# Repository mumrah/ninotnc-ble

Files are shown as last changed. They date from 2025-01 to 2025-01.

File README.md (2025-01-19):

# NinoTNC BLE Expansion Board

This project brings robust and bi-directional Bluetooth connectivity to the
best amateur radio TNC on the market, the [NinoTNC](https://tarpn.net/t/nino-tnc/nino-tnc.html). This allows for the deployment of robust bi-directional APRS
at a low cost and in the DIY ham spirit.

The total cost for setting up an APRS mobile station using this project 
(excluding radio and antenna system) is around $80. 

* NinoTNC ($45 for DIY, more for pre-built)
* NinoBLE Expansion Board ($25 for pre-built, coming soon...)
* Custom TNC cable (free/cheap for DIY)
* APRS App (aprs.fi for iOS, APRSDroid for Android)

NinoTNC BLE Intro (https://youtu.be/kItOS-uezck "NinoTNC BLE Intro")

This project is experimental and should be considered as-is. The hardware and
firmware are open source licensed under the permissive MIT License.

# Features

* iOS and Android support
* Bi-directional APRS (receive and transmit)
* High-quality AFSK modulation, thanks to the NinoTNC
* USB powered using the USB-B connector on the NinoTNC
* Data logging to an on-board SD card
* Optional user-installed OLED display for packet information
* Pass-through mode for updating NinoTNC firmware

# Use Cases

## Mobile APRS

The most obvious and indeed the primary use case of this project. When set up
as described here, this board enables a very robust mobile APRS solution. Since
the NinoTNC is compatible with a wide range of 2m mobile radios (including
surplus commercial radios), the cost of the system can be kept low. 

The use of Bluetooth also allows for a "wireless" installation. There are no 
cables connected to the phone besides a charger. This allows for an arbitrary 
separation between the mobile phone and the TNC. The wireless range of the 
NinoBLE far exceeds any distance possible within a vehicle. 

## APRS Data Logging

The SD card located on the NinoBLE will log all packets sent and received.
This is quite useful when driving since logging in the APRS apps will
eventually roll off.

Each time the NinoBLE starts up, a new log file is created. This makes it
easy to find the most recent data, but also to retain the old data.

On-board data logging can also be useful for repeater operators who
occasionally have errant APRS traffic on their VHF repeaters. Logging
everything into the SD card makes it trivial to see who was accidentally
sending APRS traffic over the repeater.

## Portable APRS

If used with an HT, the NinoBLE can be used for portable APRS tracking. 
Since the APRS mobile apps use the phone's GPS, it is quite simple
to take this system into the field.

The same benefits of the Mobile APRS use case apply here. We can use 
inexpensive radios thanks to the high-quality DSP performed by the NinoTNC.

If the NinoBLE is equipped with the optional OLED screen, the NinBLE can be
used as a simple APRS receiver without a mobile phone.

## How it works

The primary function that this board adds to the NinoTNC is Bluetooth 
connectivity. There are many use cases for this besides APRS, but for now APRS 
is the focus of this project.

The expansion board is called the NinoBLE and connects physically to the NinoTNC
through the J5 header located under the USB to UART bridge. The NinoBLE board
replaces the USB to UART bridge that is normally installed on the TNC (at U4).

As KISS packets are received by the expansion board over Bluetooth, they are
decoded and forwarded to the UART interface. Similarly, when KISS data is
received over the UART, it is decoded and forwarded to the Bluetooth interface.

An optional SD card may be installed to capture the packets as they are sent andreceived.

## Hacking

The physical layout of the board is the only thing specific to the NinoTNC 
about this project. The electrical interface between the TNC and the expansion
board is 57600 baud UART and the data protocol used is KISS. This means that 
this project can be used to add Bluetooth to any KISS TNC that uses a UART.

The heart of this project is a RaspberryPi Pico W. Many of the GPIOs are unused,
so there is plenty of opportunity for expansion and tinkering.

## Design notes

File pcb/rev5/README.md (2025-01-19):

NinoTNC BLE rev5

The pogo pins (JLCPCB part number C5157269) are listed as Economy PCBA, but
really require Standard PCBA which is quite a bit more expensive. Also, the 
PCBA process for these pins is not super precise. All the boards I received 
had slight alignment issues. If you order this board, be sure to check the pins
for shorts.

In the next revision, I will source a different part for the pogo connector.

Files under the "fabrication" can be used for JLCPCB.

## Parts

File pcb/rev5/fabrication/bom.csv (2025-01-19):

Designator | Footprint | Quantity | Value | LCSC Part #
C1, C2 | 0805 | 2 | C | C28233
J1, J2, J6, J7 | Pin_D1.0mm_4.0mm_POGO | 4 | Conn_01x01 | C5157269
J3 | NinoTNC_No_J5 | 1 | Conn_01x01
J4 | SSD1306-0.91-OLED-4pin-128x32 | 1 | Conn_01x04
J5 | TF-01A | 1 | TF-01A | C91145
R1, R2 | 0805 | 2 | 10k | C17414
SW1 | SW_SPDT_CK_JS102011SAQN | 1 | SW_SPDT | C221660
SW2 | Panasonic_EVQPUL_EVQPUC | 1 | SW_Push | C79175
U1 | RPi_Pico_W_SMD_TH | 1 | Pico

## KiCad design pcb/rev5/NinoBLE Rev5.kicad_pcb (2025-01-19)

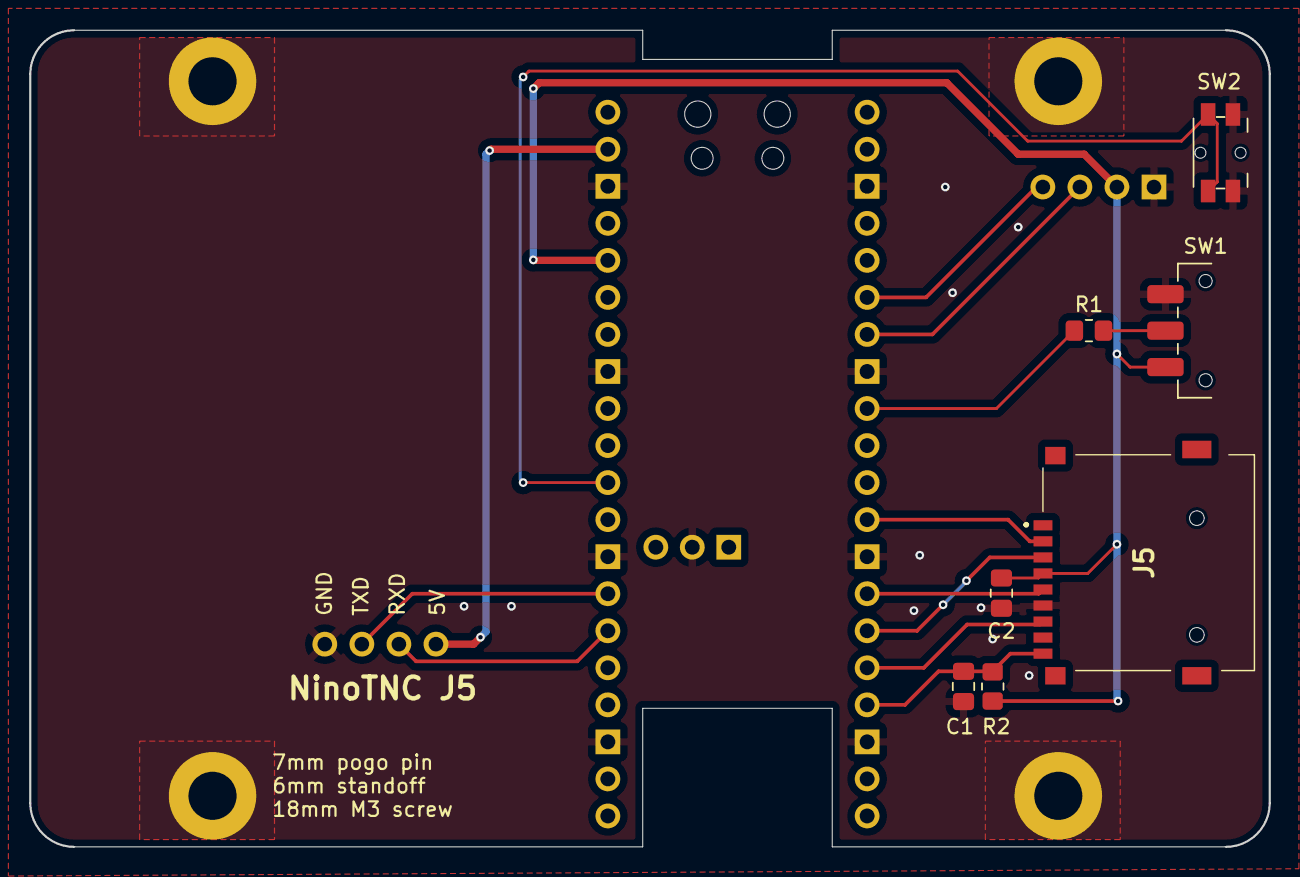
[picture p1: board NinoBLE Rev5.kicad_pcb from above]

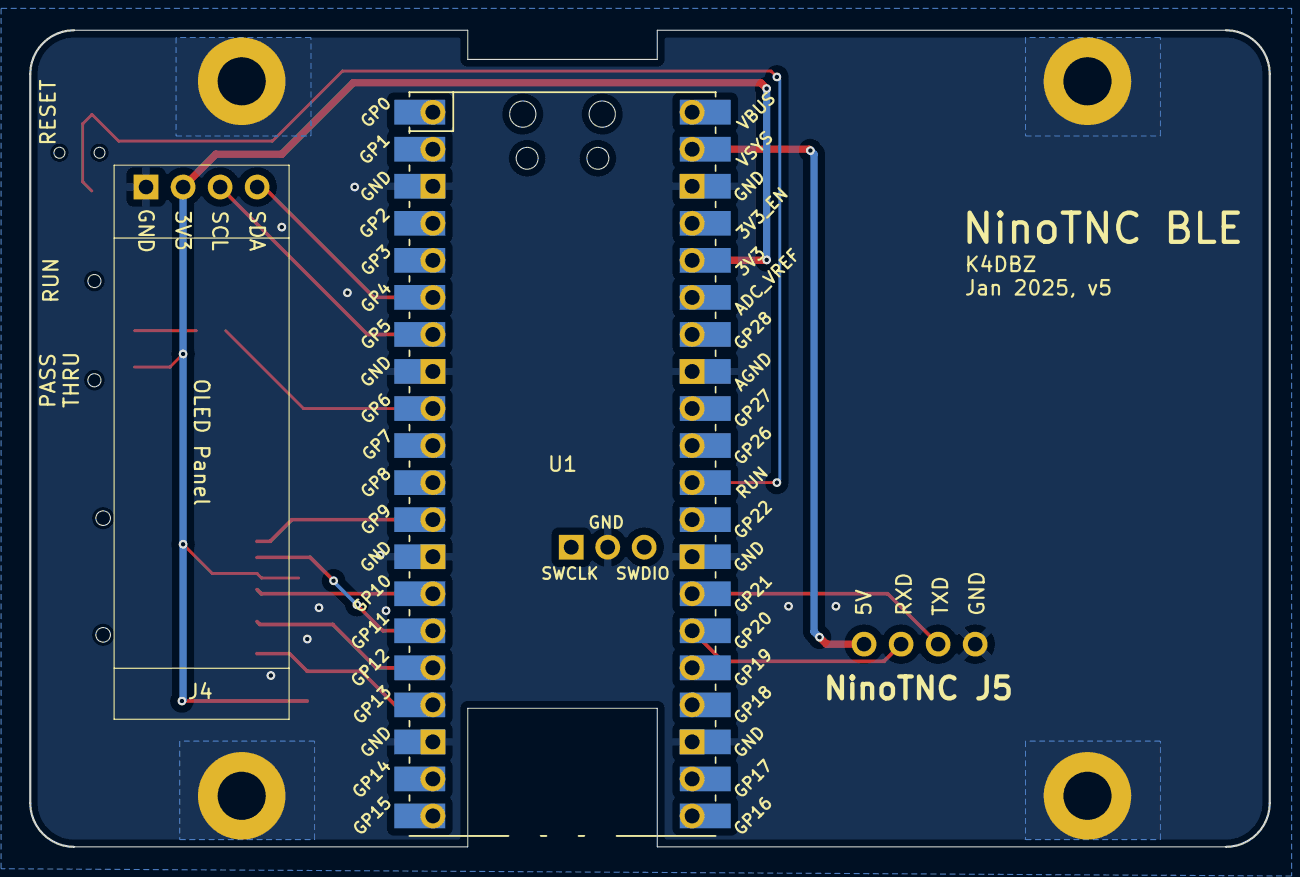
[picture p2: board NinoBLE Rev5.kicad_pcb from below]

Board: 2 copper layers, 85.0 x 56.0 mm, 14 parts (2 on the bottom side), 15 nets.

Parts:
C1, C2: C; C_0805_2012Metric_Pad1.18x1.45mm_HandSolder
J1, J2, J6, J7: Conn_01x01; Pin_D1.0mm_4.0mm_POGO
J3: Conn_01x01; NinoTNC_No_J5
J4: Conn_01x04; SSD1306-0.91-OLED-4pin-128x32
J5: TF-01A
R1, R2: 10k; R_0805_2012Metric_Pad1.20x1.40mm_HandSolder
SW1: SW_SPDT; SW_SPDT_CK_JS102011SAQN
SW2: SW_Push; Panasonic_EVQPUL_EVQPUC
U1: Pico; RPi_Pico_W_SMD_TH

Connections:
3V3: C2.1, J4.2, J5.4 (VDD), R2.2, SW1.1 (A), U1.36 (3V3)
5V: J7.1, U1.39 (VSYS)
/SPI1_CS: J5.2 (CD/DAT3), U1.12 (GPIO9)
/SPI1_RX: J5.7 (DAT0), U1.16 (GPIO12)
/SPI1_SCK: J5.5 (CLK), U1.14 (GPIO10)
/SPI1_TX: J5.3 (CMD), U1.15 (GPIO11)
GND: C1.2, C2.2, J1.1, J3.1, J4.1, J5.6 (VSS), SW1.3 (C), SW2.1, U1.3 (GND), U1.8 (GND), U1.13 (GND), U1.18 (GND), U1.23 (GND), U1.28 (GND), U1.33 (AGND), U1.38 (GND), U1.42 (GND)
MODE_SEL: R1.1, U1.9 (GPIO6)
unnamed: R1.2, SW1.2 (B)
RUN: SW2.2, U1.30 (RUN)
RXD: J6.1, U1.26 (GPIO20)
SCL: J4.3, U1.7 (GPIO5)
SDA: J4.4, U1.6 (GPIO4)
SD_CD: C1.1, J5.CD, R2.1, U1.17 (GPIO13)
TXD: J2.1, U1.27 (GPIO21)

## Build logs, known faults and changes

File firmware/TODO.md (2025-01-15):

General
=======
Configure operation mode over serial
Configure operator callsign over serial
Store config in flash
Logging system? How to easily enable/disable verbose logging (at runtime?)

KISS
====
- [ ] Ack mode
- [ ] Reset after timeout
- [ ] Flow control. When using ack mode, need to not exceed some number of in-flight bytes

AX25
====
AX.25 digipeater
* Parse AX.25 packets
* Src/dest call, repeaters
* Beacon telemetry (number of packets, uptime, etc)

APRS
====
* Capture our position from TX'd APRS beacons
* Display distance and heading of incoming packets

NinoTNC
=======
Add mode for updating NinoTNC flash
Communicate with multiple TNCs over USB?

USB
===
https://hackaday.com/2022/12/28/usb-host-on-rp2040-with-pio/
https://github.com/sekigon-gonnoc/Pico-PIO-USB

Successfull BLE connection

ATT connected. address=20041d80 type=1 handle=0040
Unhandled event E7      HCI_EVENT_META_GAP
Unhandled event 3E      HCI_EVENT_LE_META
Unhandled event 3E      HCI_EVENT_LE_META
Unhandled event 3E      HCI_EVENT_LE_META
Unhandled event FF
Unhandled event 3E      HCI_EVENT_LE_META
ATT MTU exchange complete. handle=0040 MTU=255
Unhandled event 13
Unhandled event 13
Unhandled event 13
att_write_callback conn=0040 attr=0016
Unhandled event 13
Unhandled event 13
att_write_callback conn=0040 attr=0012

Rev 4
=====

* Flip Pico to bottom of board
* Use a surface mount right angle button

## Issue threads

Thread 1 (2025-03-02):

System Design understanding

aviatorhh, 2025-03-02:
Why is the pico needed? Wouldn’t a Bluetooth-TTL Module do the job also (besides SD card stuff)?
How do I compile and flash your project. Please describe.

73

Nicholas

mumrah, 2025-03-03:
A bluetooth TTL module like the HC-05 would only work with another HC-05 to act as a "wireless serial cable". It can't really interface with a phone (as far as I know). It might be possible to get things working with an HM-10 module, but I kind of doubt it. To get things working for aprs.fi (and now some experimental versions of APRSDroid), you need to set up the BLE very precisely. This is only possible with "proper" bluetooth modules like the Microchip BM70 or in my case the RPi Pico W.

The RPi Pico W was chosen for its wide availability, low cost ($6), and high number of GPIOs. The SDK documentation and examples are also very good.

To compile the project, you will need VSCode and the Pico SDK plugin. You'll want to import this source as a project and go from there.

Closed 2025-05-12.

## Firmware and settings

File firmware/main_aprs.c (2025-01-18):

/**
 * Copyright (c) 2023 Raspberry Pi (Trading) Ltd.
 *
 * SPDX-License-Identifier: BSD-3-Clause
 */

#include <stdio.h>
#include <stdbool.h>
#include "btstack.h"
#include "pico/cyw43_arch.h"
#include "pico/btstack_cyw43.h"
#include "pico/multicore.h"
#include "pico/stdlib.h"
#include "hardware/i2c.h"
#include "tusb.h"

#include "oled.h"
#include "ax25.h"
#include "aprs.h"
#include "blink.h"
#include "shell.h"
#include "kiss.h"
#include "bt.h"
#include "pconfig.h"
#include "config.h"
#include "passthru.h"
#include "logger.h"

#define UART_TX_PIN 20    // Use GPIO 20 and 21 for v5 board
#define UART_RX_PIN 21
//#define UART_TX_PIN 4
//#define UART_RX_PIN 5

AX25Call n9600a = {
    "N9600A", 4, 0, false, false
};

AX25Call cqbeep5 = {
    "CQBEEP", 5, 0, false, false
};

uint8_t scratch[400];
KissState tncKiss;
KissState bleKiss;
KissState sppKiss;
KissFrame kissFrame;
ShellState shell;
LED led;
OLED oled;
AX25Packet packet;
char line[16]; // OLED text buffer

AX25Callback rx_callback;
AX25Callback tx_callback;

// Record last beacon data that was transmitted
bool saw_our_beacon = false;
Loc last_lat;
Loc last_lon;
AX25Call last_call;

uint8_t tnc_query_firmware[] = {FEND, KISS_N9600A_VER_CMD, 0x00, FEND};
bool n9600_present = false;
char n9600a_firmware_version[5];

// Only use this inside interrupts. Should only be used for coarse grained timing estimates since it 
// gets update in the main loop which has no timing guarantees.
uint32_t async_now_ms = 0;  
uint32_t async_now_us = 0;
uint32_t last_led_update_ms;
uint32_t led_refresh_ms = 3000;

int64_t init_tnc(alarm_id_t id, __unused void *user_data) {
    uart_write_blocking(UART_ID, tnc_query_firmware, 4);
    uart_tx_wait_blocking(UART_ID);
    return 0;
}

void pretty_uptime(char * buffer, uint32_t millis) {
    if (millis < 600000) {
        // seconds up to 10 mins (600s)
        sprintf(buffer, "%ds", millis / 1000);
    } else if (millis < 43200000) {
        // minutes up to 12 hours (720m)
        sprintf(buffer, "%dm", millis / 60000);
    } else if (millis < 2592000000) {
        // hours up to 30 days (720h)
        sprintf(buffer, "%dh", millis / 3600000);
    } else {
        // days
        sprintf(buffer, "%dd", millis / 86400000);
    }
}

void log_ax25_packet(AX25Packet packet, bool rx) {
    memset(scratch, '\0', 400);
    uint8_t pos = 0;
    pos += ax25_format_call(&scratch[pos], &(packet.source_call));
    scratch[pos++] = ' ';
    pos += ax25_format_call(&scratch[pos], &(packet.dest_call));
    scratch[pos++] = ' ';
    memcpy(&scratch[pos], kissFrame.buffer, kissFrame.len);
    if (rx) {
        logger_write_ascii(async_now_ms, "RX", scratch, strlen(scratch));
    } else {
        logger_write_ascii(async_now_ms, "TX", scratch, strlen(scratch));
    }
}

int64_t send_our_info_to_bt(alarm_id_t id, __unused void *user_data) {
    AX25Call dest_call = {"APZBLE", 0, 0, true, false};
    AX25Call src_call = {"N9600", 0, 0, false, true};
    char msg[62];
    memset(msg, '\0', 62);
    strcat(msg, "NinoTNC BLE ");
    //strcat(msg, " built on ");
    //strcat(msg, BUILD_DATE);
    
    char uptime[5];
    pretty_uptime(uptime, async_now_ms);
    strcat(msg, uptime);
    strcat(msg, " ");
    strcat(msg, GIT_SHORT_HASH);


    if (n9600_present) {
        strcat(msg, " ");
        strcat(msg, n9600a_firmware_version);
    }

    uint16_t len = aprs_status(kissFrame.buffer, &src_call, &dest_call, msg);
    kissFrame.len = len;
    kissFrame.hdlc = 0;
    kissFrame.type = KISS_DATA;
    len = kiss_encode(&kissFrame, scratch);
    handle_tnc_rx_data(scratch, len);
    return 0;
}

void ble_connection_callback(bool disconnected) {
    printf("ble_connection_callback(%d)\n", disconnected);
    if (!disconnected) {
        logger_write_ascii(async_now_ms, "BLE", "Connected", 10);
        add_alarm_in_ms(500, send_our_info_to_bt, NULL, true);
    } else {
        logger_write_ascii(async_now_ms, "BLE", "Disconnected", 13);
    }
}

void spp_pin_callback(uint32_t pin) {
    oled_clear(&oled);
    oled_write_string(&oled, 0, 0, "Bluetooth PIN");
    char pin_str[8];
    sprintf(pin_str, "%06lu", pin);
    oled_write_string(&oled, 5, 16, pin_str);
    oled_render(&oled);
}

void display_aprs_packet_oled(AX25Packet * packet, uint8_t * buffer, uint16_t len, bool rx) {
    oled_clear(&oled);
    memset(line, ' ', sizeof(line));
    if (rx) {
        memcpy(line, "RX", 2);
    } else {
        memcpy(line, "TX", 2);
    }
    AX25FrameType frame_type = ax25_frame_type(packet, buffer);
    bool found_aprs = false;
    char aprs_type;
    switch (frame_type) {
        case AX25_UNNUMBERED:
            AX25UnnumberedFrameType u_subtype = ax25_u_subtype(packet, buffer);
            if (u_subtype != AX25_U_UI) {
                memcpy(&line[3], "Not UI", 7);
                break;
            }
            AX25PidType pid_type = ax25_packet_pid_field(packet, buffer);
            if (pid_type != AX25_PID_NO_LAYER_3) {
                memcpy(&line[3], "Bad PID", 8);
                break;
            }
            aprs_type = aprs_data_type(packet, buffer);
            printf("APRS type: %02x\n", aprs_type);
            line[3] = aprs_type;
            if (aprs_type == APRS_TYPE_POS_TIME_NOMSG || aprs_type == APRS_TYPE_POS_TIME_MSG) {
                aprs_datetime_t dt = aprs_time(packet, buffer);
                sprintf(&line[7], "%02d:%02d:%02dZ", dt.hour, dt.min, dt.sec);
            }            
            found_aprs = true;
            break;
        case AX25_INFORMATION:
        case AX25_SUPERVISORY:
        default:
            memcpy(&line[3], "Not UI", 7);
            break;
    }
    oled_write_string(&oled, 0, 0, line);
    memset(line, ' ', sizeof(line));
    ax25_format_call(line, &(packet->source_call));

    oled_write_string(&oled, 0, 8, line);

    // If not APRS, bail out
    if (!found_aprs) {
        oled_render(&oled);
        return;
    }

    // If it looks like the Test TX, bail out 
    if (ax25_call_eq(&(packet->source_call), &n9600a) && ax25_call_eq(&(packet->dest_call), &cqbeep5)) {
        oled_write_string(&oled, 0, 16, "Test TX button");
        oled_write_string(&oled, 0, 24, n9600a_firmware_version);
        oled_render(&oled);

        add_alarm_in_ms(500, send_our_info_to_bt, NULL, true);
        return;
    }

    //aprs_comment(packet, buffer, len, scratch);
    memset(line, ' ', sizeof(line));

    // Parse the lat/lon
    Loc lat, lon;
    bool has_loc;
    if (aprs_type == APRS_TYPE_POS_NOTIME_NOMSG || aprs_type == APRS_TYPE_POS_NOTIME_MSG) {
        aprs_notime_latitude(packet, buffer, &lat);
        aprs_notime_longitude(packet, buffer, &lon);
        has_loc = true;
    } else if (aprs_type == APRS_TYPE_POS_TIME_NOMSG || aprs_type == APRS_TYPE_POS_TIME_MSG) {
        aprs_time_latitude(packet, buffer, &lat);
        aprs_time_longitude(packet, buffer, &lon);
        has_loc = true;
    } else {
        // ignore
        has_loc = false;
    }
    
    if (!rx) {
        // If BLE is sending a beacon, grab out callsign and position
        if (aprs_type == APRS_TYPE_POS_TIME_MSG || aprs_type == APRS_TYPE_POS_NOTIME_NOMSG) {
            saw_our_beacon = true;
            memcpy(&last_lat, &lat, sizeof(lat));
            memcpy(&last_lon, &lon, sizeof(lon));
            ax25_call_cpy(&last_call, &packet->source_call);
            printf("Update last call to %s-%d\n", last_call.callsign, last_call.ssid);
        }
    } else {
        // If receiving a beacon, print the lat/lon, distance, and heading
        if (has_loc) {
            // Print the lat/lon
            printf("lat: %d %d %d\n", lat.deg, lat.min, lat.sec);
            print_loc_dd(&lat, line);
            line[6] = ' ';
            printf("lon: %d %d %d\n", lon.deg, lon.min, lon.sec);
            print_loc_dd(&lon, &line[7]);
            oled_write_string(&oled, 0, 16, line);

            // Display the great circle distance
            if (saw_our_beacon) {
                double lat1_dd = loc_dd(&last_lat);
                double lon1_dd = loc_dd(&last_lon);
                double lat2_dd = loc_dd(&lat);
                double lon2_dd = loc_dd(&lon);
                double d_km = loc_distance(lat1_dd, lon1_dd, lat2_dd, lon2_dd);
                memset(line, ' ', sizeof(line));
                sprintf(line, "%0.2fkm", d_km);
                // TODO heading
                oled_write_string(&oled, 0, 24, line);
            }
        }
    }

    oled_render(&oled);
}

void display_ax25_packet_oled(AX25Packet * packet, uint8_t * buffer, bool rx) {
    oled_clear(&oled);
    if (rx) {
        oled_write_string(&oled, 0, 0, "RX");
    } else {
        oled_write_string(&oled, 0, 0, "TX");
    }
    AX25FrameType frame_type = ax25_frame_type(packet, buffer);
    switch (frame_type) {
        case AX25_INFORMATION:
            oled_write_string(&oled, 24, 0, "I");
            break;
        case AX25_UNNUMBERED:
            oled_write_string(&oled, 24, 0, "U");
            AX25UnnumberedFrameType u_subtype = ax25_u_subtype(packet, buffer);
            oled_write_string(&oled, 40, 0, unnumbered_frame_type_names[u_subtype]);
            AX25PidType pid_type = ax25_packet_pid_field(packet, buffer);
            oled_write_string(&oled, 64, 0, pid_type_names[pid_type]);
            break;
        case AX25_SUPERVISORY:
            oled_write_string(&oled, 24, 0, "S");
            break;
    }

    memset(line, ' ', sizeof(line));
    uint8_t len = ax25_format_call(&line[5], &(packet->source_call));
    line[5 + len] = ' ';
    line[6 + len] = '>';
    oled_write_string(&oled, 0, 16, line);
    memset(line, ' ', sizeof(line));
    ax25_format_call(&line[5], &(packet->dest_call));
    oled_write_string(&oled, 0, 24, line);
    oled_render(&oled);
}

void display_rx_packet(AX25Packet * packet, uint8_t * buffer, uint16_t len) {
    display_aprs_packet_oled(packet, buffer, len, true);
}

void display_tx_packet(AX25Packet * packet, uint8_t * buffer, uint16_t len) {
    display_aprs_packet_oled(packet, buffer, len, false);
}


void wifi_led_toggle(bool on) {
    cyw43_arch_gpio_put(CYW43_WL_GPIO_LED_PIN, on);
}

/**
 * UART RX interrupt handler. Called as we receive bytes from the TNC. We feed these into 
 * a KISS parser
 */
void on_uart_rx() {
    while (uart_is_readable(UART_ID)) {
        uint8_t ch = uart_getc(UART_ID);
        //printf("uart: %02X\n", ch);
        // Only feed a byte to kiss parser if there is not a frame ready.
        if (!tncKiss.haveFrame) {
            kiss_feed(&tncKiss, ch, async_now_ms);
        }  
    }
}

/**
 * Called when BLE has data ready for us. This is called from the main loop.
 * 
 * Stream the data through the KISS parser to ensure a valid frame was received. 
 * This also allows us to handle a KISS packet that exceeds the BLE packet size.
 * 
 * @param buffer pointer to the BLE TX buffer
 * @param len    number of valid bytes in the buffer
 */
static void ble_write_callback(uint8_t * buffer, uint16_t len) {
    for (uint16_t i=0; i<len; i++) {
        //printf("BLE: %02X\n", buffer[i]);
        if (kiss_feed(&bleKiss, buffer[i], async_now_ms)) {
            kiss_read(&bleKiss, &kissFrame);

            // Copy the KISS frame into a separate buffer for writing to the UART
            uint16_t encoded_len = kiss_encode(&kissFrame, scratch);
            printf("Got valid KISS from BLE, sending to TNC\n");

            uart_write_blocking(UART_ID, scratch, encoded_len);
            uart_tx_wait_blocking(UART_ID);

            // decode and display the packet
            if (ax25_init(&packet, kissFrame.buffer, kissFrame.len)) {
                tx_callback(&packet, kissFrame.buffer,  kissFrame.len);
            }

            logger_write_pcap(async_now_ms, async_now_us, "TX", kissFrame.buffer,  kissFrame.len);
            log_ax25_packet(packet, false);

            kiss_init(&bleKiss, async_now_ms);
        }
    }

}

/**
 * Called when SPP has data ready for us. This is called from the BTStack thread.
 * 
 * Stream the data through the KISS parser to ensure a valid frame was received. 
 * 
 * @param buffer pointer to the SPP TX buffer
 * @param len    number of valid bytes in the buffer
 */
static void spp_write_callback(uint8_t * buffer, uint16_t len) {
    // TODO this is called from BTStack. Consider deferring the the UART write until our main loop
    for (uint16_t i=0; i<len; i++) {
        //printf("BLE: %02X\n", buffer[i]);
        if (kiss_feed(&sppKiss, buffer[i], async_now_ms)) {
            kiss_read(&sppKiss, &kissFrame);

            // Copy the KISS frame into a separate buffer for writing to the UART
            uint16_t encoded_len = kiss_encode(&kissFrame, scratch);
            printf("Got valid KISS from SPP, sending to TNC\n");
            
            uart_write_blocking(UART_ID, scratch, encoded_len);
            uart_tx_wait_blocking(UART_ID);

            // decode and display the packet
            if (ax25_init(&packet, kissFrame.buffer, kissFrame.len)) {
                tx_callback(&packet, kissFrame.buffer,  kissFrame.len);
            }

            logger_write_pcap(async_now_ms, async_now_us, "TX", kissFrame.buffer,  kissFrame.len);
            log_ax25_packet(packet, false);

            kiss_init(&sppKiss, async_now_ms);
        }
    }

}

void init_uart(irq_handler_t uart_irq, bool enable_fifos) {
    // UART init
     // Set up our UART with a basic baud rate.
    uart_init(UART_ID, 57600);

    // Set the TX and RX pins by using the function select on the GPIO
    // Set datasheet for more information on function select
    gpio_set_function(UART_TX_PIN, UART_FUNCSEL_NUM(UART_ID, UART_TX_PIN));
    gpio_set_function(UART_RX_PIN, UART_FUNCSEL_NUM(UART_ID, UART_RX_PIN));

    // Set UART flow control CTS/RTS, we don't want these, so turn them off
    uart_set_hw_flow(UART_ID, false, false);

    // Set our data format
    uart_set_format(UART_ID, DATA_BITS, STOP_BITS, PARITY);

    // Turn on FIFO's
    uart_set_fifo_enabled(UART_ID, enable_fifos);

    // Set up a RX interrupt
    // We need to set up the handler first
    // Select correct interrupt for the UART we are using
    int UART_IRQ = UART_ID == uart0 ? UART0_IRQ : UART1_IRQ;

    // And set up and enable the interrupt handlers
    irq_set_exclusive_handler(UART_IRQ, uart_irq);
    irq_set_enabled(UART_IRQ, true);

    // Now enable the UART to send interrupts - RX only
    uart_set_irq_enables(UART_ID, true, false);
}

static uint8_t spp_service_buffer[150];       // Used for SPP record

bool uart_readable() {
    return uart_is_readable(UART_ID);
}

uint32_t uart_read() {
    return uart_getc(UART_ID);
}

uint32_t uart_writer(const void * buffer, uint32_t len) {
    uart_write_blocking(UART_ID, buffer, len);
    //uart_tx_wait_blocking(UART_ID);
    return len;
}

bool check_passthru_enabled() {
    bool passthrough_sw = false;

    gpio_init(PASSTHRU_SW_PIN);
    gpio_set_dir(PASSTHRU_SW_PIN, 0); // input

    absolute_time_t time = get_absolute_time();
    uint32_t start_ms = to_ms_since_boot(time);
    uint32_t now_ms;
    while (gpio_get(PASSTHRU_SW_PIN)) {
        // If GPIO 26 is held high for 100ms, enter passthrough mode
        time = get_absolute_time();
        now_ms = to_ms_since_boot(time);
        if (now_ms - start_ms > 100) {
            passthrough_sw = true;
            break;
        }
    }

    return passthrough_sw;
}

void passthru_usb_entry(void) {
    while (1) {
        passthru_usb_read(tud_cdc_available, tud_cdc_read);
        passthru_usb_write(tud_cdc_write_available, tud_cdc_write, tud_cdc_write_flush);
    }
}
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
int main() {
    // Minimal boot-up before checking run mode
    stdio_init_all();
    if (cyw43_arch_init()) {
        return -1;
    }

    if (!check_passthru_enabled()) {
        // If not in "passthru" mode, run the main loop
        return run_main_loop();
    } else {
        // If we detect the passthru mode, clear the OLED
        oled_init(&oled);
        oled_deinit(&oled);

        // Then flash the LED and leave it solid
        cyw43_arch_gpio_put(CYW43_WL_GPIO_LED_PIN, 1);
        sleep_ms(50);
        cyw43_arch_gpio_put(CYW43_WL_GPIO_LED_PIN, 0);
        sleep_ms(50);
        cyw43_arch_gpio_put(CYW43_WL_GPIO_LED_PIN, 1);

        // Init the UART for passthru mode
        passthru_init(uart_readable, uart_read);
        init_uart(passthru_uart_irq, false);

        // Use second core for USB loop
        multicore_launch_core1(passthru_usb_entry);

        // Main core for UART loop
        while (1) {
            passthru_uart_loop(uart_writer);
        }
        return 0;
    }
}

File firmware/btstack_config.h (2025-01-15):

#ifndef _PICO_BTSTACK_BTSTACK_CONFIG_H
#define _PICO_BTSTACK_BTSTACK_CONFIG_H


// BTstack features that can be enabled
#define ENABLE_LE_PERIPHERAL

#define ENABLE_LOG_INFO
#define ENABLE_LOG_ERROR
#define ENABLE_PRINTF_HEXDUMP
#define ENABLE_SCO_OVER_HCI

//#define ENABLE_CROSS_TRANSPORT_KEY_DERIVATION

// BTstack configuration. buffers, sizes, ...
#define HCI_OUTGOING_PRE_BUFFER_SIZE 4
#define HCI_ACL_PAYLOAD_SIZE (1691 + 4)
#define HCI_ACL_CHUNK_SIZE_ALIGNMENT 4
#define MAX_NR_AVDTP_CONNECTIONS 1
#define MAX_NR_AVDTP_STREAM_ENDPOINTS 1
#define MAX_NR_AVRCP_CONNECTIONS 2
#define MAX_NR_BNEP_CHANNELS 1
#define MAX_NR_BNEP_SERVICES 1
#define MAX_NR_BTSTACK_LINK_KEY_DB_MEMORY_ENTRIES  2
#define MAX_NR_GATT_CLIENTS 1
#define MAX_NR_HCI_CONNECTIONS 2
#define MAX_NR_HID_HOST_CONNECTIONS 1
#define MAX_NR_HIDS_CLIENTS 1
#define MAX_NR_HFP_CONNECTIONS 1
#define MAX_NR_L2CAP_CHANNELS  4
#define MAX_NR_L2CAP_SERVICES  3
#define MAX_NR_RFCOMM_CHANNELS 1
#define MAX_NR_RFCOMM_MULTIPLEXERS 1
#define MAX_NR_RFCOMM_SERVICES 1
#define MAX_NR_SERVICE_RECORD_ITEMS 4
#define MAX_NR_SM_LOOKUP_ENTRIES 3
#define MAX_NR_WHITELIST_ENTRIES 16
#define MAX_NR_LE_DEVICE_DB_ENTRIES 16

// Limit number of ACL/SCO Buffer to use by stack to avoid cyw43 shared bus overrun
#define MAX_NR_CONTROLLER_ACL_BUFFERS 3
#define MAX_NR_CONTROLLER_SCO_PACKETS 3

// Enable and configure HCI Controller to Host Flow Control to avoid cyw43 shared bus overrun
#define ENABLE_HCI_CONTROLLER_TO_HOST_FLOW_CONTROL
#define HCI_HOST_ACL_PACKET_LEN 1024
#define HCI_HOST_ACL_PACKET_NUM 3
#define HCI_HOST_SCO_PACKET_LEN 120
#define HCI_HOST_SCO_PACKET_NUM 3

// Link Key DB and LE Device DB using TLV on top of Flash Sector interface
#define NVM_NUM_DEVICE_DB_ENTRIES 16
#define NVM_NUM_LINK_KEYS 16

// We don't give btstack a malloc, so use a fixed-size ATT DB.
#define MAX_ATT_DB_SIZE 512

// BTstack HAL configuration
#define HAVE_EMBEDDED_TIME_MS

// map btstack_assert onto Pico SDK assert()
#define HAVE_ASSERT

// Some USB dongles take longer to respond to HCI reset (e.g. BCM20702A).
#define HCI_RESET_RESEND_TIMEOUT_MS 1000

#define ENABLE_SOFTWARE_AES128
#define ENABLE_MICRO_ECC_FOR_LE_SECURE_CONNECTIONS

#define HAVE_BTSTACK_STDIN

// To get the audio demos working even with HCI dump at 115200, this truncates long ACL packets
//#define HCI_DUMP_STDOUT_MAX_SIZE_ACL 100

#endif // _PICO_BTSTACK_BTSTACK_CONFIG_H

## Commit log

2025-01-18 add pcb
    [NinoBLE Rev5.kicad_pcb, NinoBLE Rev5.kicad_sch]
2025-01-19 fixup rev5 pcb files
    [NinoBLE Rev5.kicad_pcb, NinoBLE Rev5.kicad_sch, bom.csv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]
2025-07-02 Get things working with Packet Commander
    * Only decode AX.25 from KISS DATA frames
    * Add mutex to protect buffers shared by the two cores
    * Add guard against infinite loop in AX.25 decoder
    * Allow multiple KISS frames to be buffered instead of just one
